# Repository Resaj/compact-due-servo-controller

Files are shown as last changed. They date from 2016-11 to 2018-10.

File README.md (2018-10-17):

# Compact Due servo controller
This is a redesigned Arduino Due for the control of any humanoid or articulated robot, controlled by PS3 bluetooth controller, with bluetooth dongle in the native port of the SAM3 microcontroller, 20 servomotor signals, UART and I2C for bus servomotors.

<p align="center">
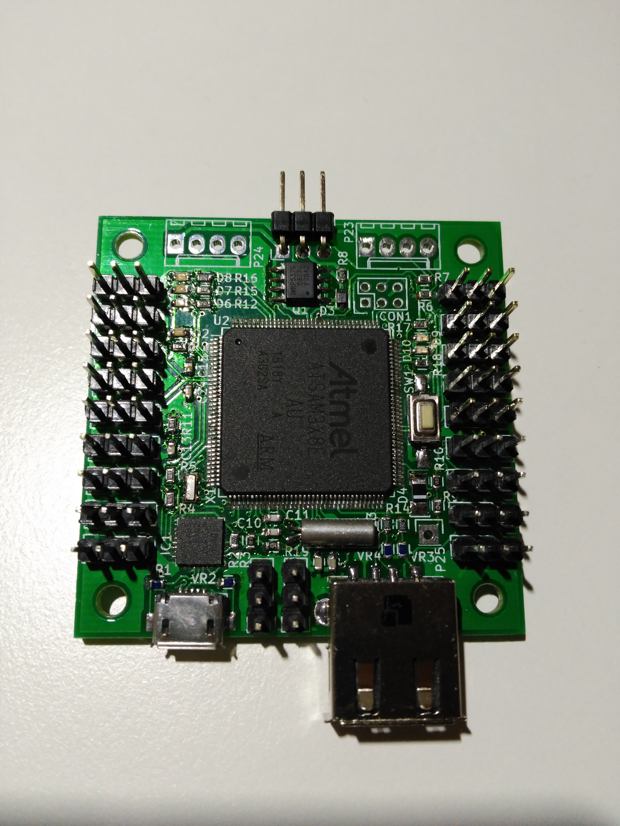
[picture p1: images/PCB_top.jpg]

</p>

<p align="center">
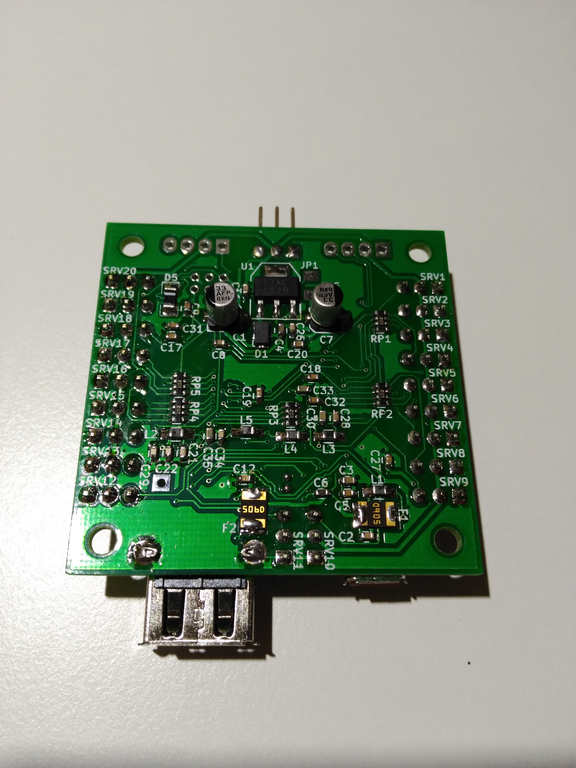
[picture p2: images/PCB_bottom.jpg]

</p>

<p align="center">
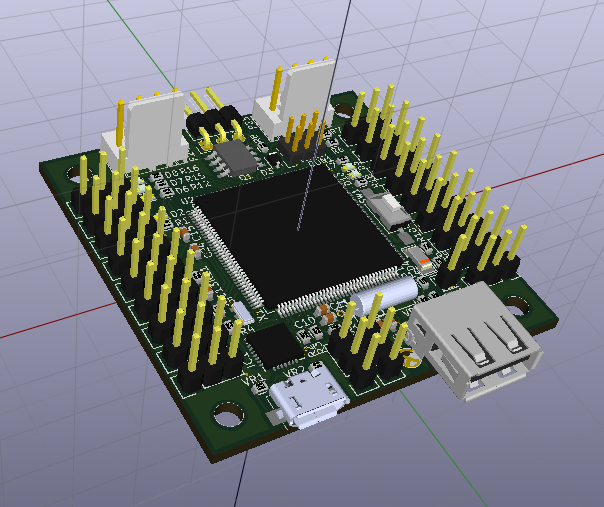
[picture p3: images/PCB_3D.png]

</p>

## Authors
[Rubén Espino San José](https://github.com/Resaj)

[Mario Luis Álvarez Pastor](https://github.com/AxomirUxsil)

## License
<p align="center">

</p>

Todos estos productos están liberados mediante [Creative Commons Attribution-ShareAlike 4.0 International License](http://creativecommons.org/licenses/by-sa/4.0/).  
_All these products are released under [Creative Commons Attribution-ShareAlike 4.0 International License](http://creativecommons.org/licenses/by-sa/4.0/)._

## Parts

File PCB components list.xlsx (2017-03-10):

Needed | Component | Quantity | Price per unit (€) | Total price (€) | Link
1 | diode SS1P3L | 50 | 0.079 | 3.95 | http://es.rs-online.com/web/p/diodos-schottky-y-rectificadores/7103695/
2 | capacitor 33uF | 10 | 0.114 | 1.14 | http://es.rs-online.com/web/p/condensadores-de-aluminio/0568852/
1 | MOSFET IRF7842PBF | 5 | 1.652 | 8.26 | http://es.rs-online.com/web/p/transistores-mosfet/6886879/
1 | zéner MM3Z12VT1G | 25 | 0.113 | 2.825 | http://es.rs-online.com/web/p/diodos-zener/6878219/
5 | array 4 resistor 0603 1k | 50 | 0.037 | 1.85 | http://es.rs-online.com/web/p/array-de-resistencias/5225579/
1 | conector uUSB SMD | 5 | 0.414 | 2.07 | http://es.rs-online.com/web/p/conectores-micro-usb/7142344/
2 | PTC 500mA | 10 | 0.306 | 3.06 | http://es.rs-online.com/web/p/fusibles-para-montaje-superficial-rearmables/6478156/
5 | PTC CG0603MLC-05LE | 25 | 0.106 | 2.65 | http://es.rs-online.com/web/p/varistores-de-oxido-metalico/6909938/
3 | inductor BLM21 | 25 | 0.021 | 0.525 | http://es.rs-online.com/web/p/nucleos-de-ferrita/7926300/
1 | driver CP2102-GM | 1 | 2.48 | 2.48 | http://es.rs-online.com/web/p/products/5268841/
1 | conector USB | 1 | 0.7 | 0.7 | http://es.rs-online.com/web/p/conectores-usb-tipo-a/7378791/
1 | diode CD1206-S01575 | 100 | 0.0326 | 3.26 | http://es.rs-online.com/web/p/diodos-schottky-y-rectificadores/7734514/
1 | uC ATSAM3X8E | 1 | 10.94 | 10.94 | http://es.rs-online.com/web/p/microcontroladores/7692527/
1 | resonator CSTCE12M0G15L99-R0 | 5 | 0.288 | 1.44 | http://es.rs-online.com/web/p/resonadores-ceramicos/7926527/
1 | crystal 32,768MHz | 10 | 0.40414 | 4.0414 | http://es.rs-online.com/web/p/unidades-de-cristal/5476985/
1 | LDO 3V3 LM3940IMP | 1 | 1.4399 | 1.4399 | http://es.rs-online.com/web/p/reguladores-de-tension-de-baja-caida/5361546/
1 | pushbutton SMD | 10 | 0.041 | 0.41 | https://es.aliexpress.com/store/product/10-100-pieces-lot-New-type-3-6-2-5-switch-SMD-smt-3x6x2-5mm/1248738_32714250239.html
IMPORTANT NOTES: |  | Resistors, capacitors and leds (all SMD 0603) haven't been included because buying them in kits in eBay or Aliexpress is cheaper
 |  | The list of components has been designed to make purchases cost-effective from 3 assemblied PCBs. For smaller purchases, look for another distributor
 |  |  | Subtotal (€) | 51.0413
 |  |  | Shipping cost (€) | 6.05
 |  |  | Total (€) | 57.0913

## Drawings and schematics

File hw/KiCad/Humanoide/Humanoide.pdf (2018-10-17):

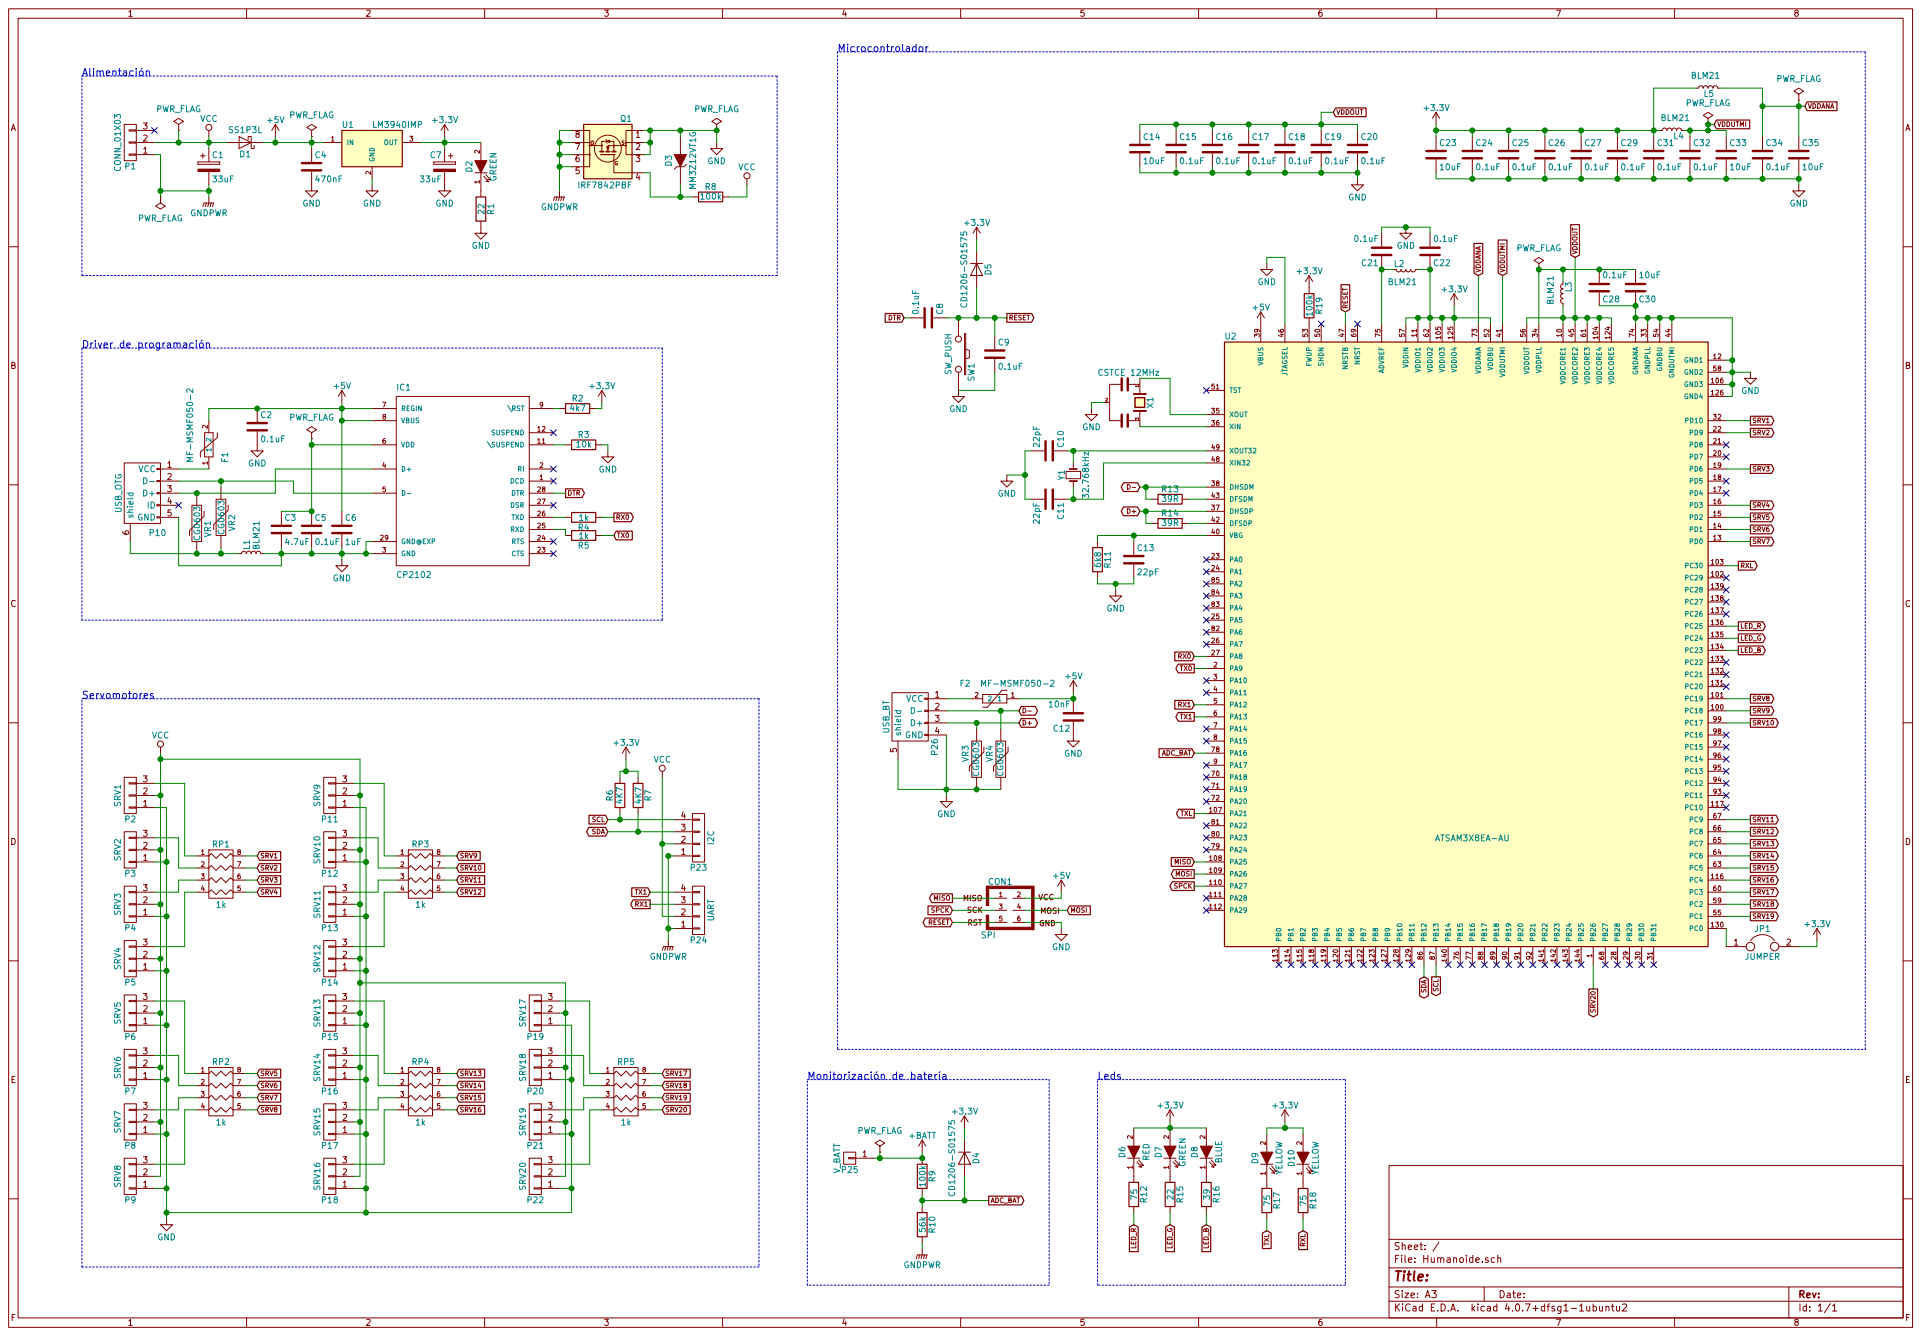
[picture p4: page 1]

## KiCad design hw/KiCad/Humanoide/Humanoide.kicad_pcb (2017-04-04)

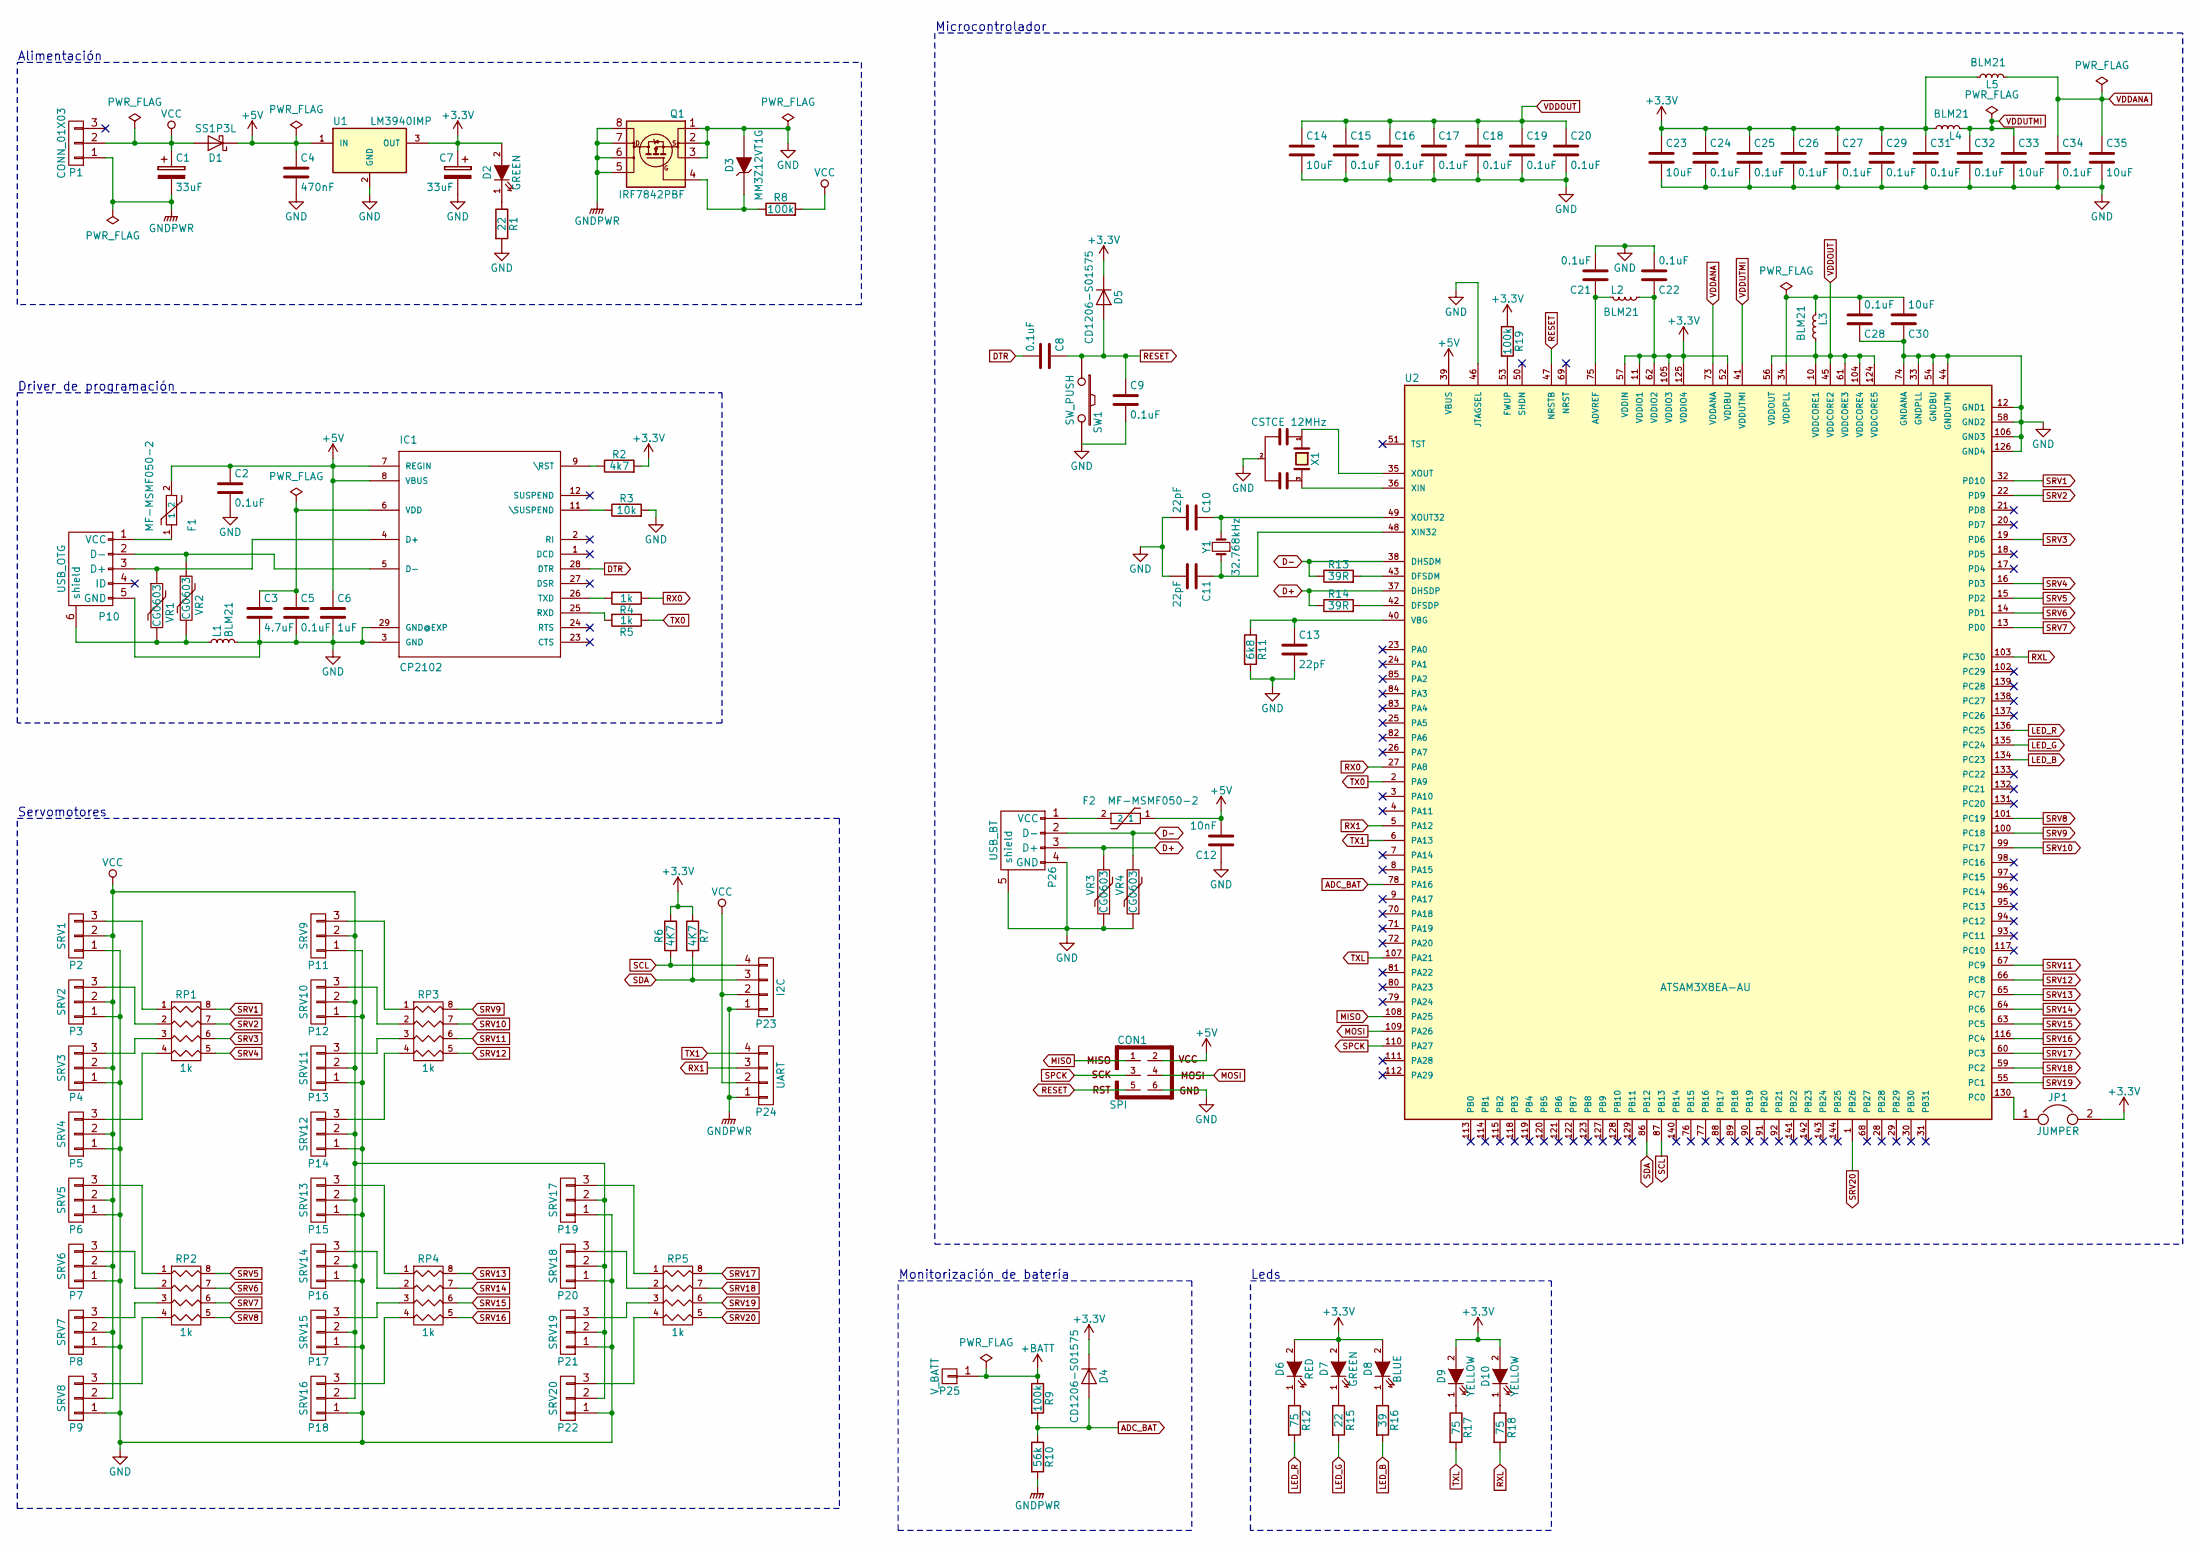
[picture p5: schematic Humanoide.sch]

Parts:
C1, C7: 33uF; c_elec_4x4.5
C2, C5, C8, C9, C15, C16, C17, C18, C19, C20, C21, C22, C24, C25, C26, C27, C28, C29, C31, C32, C34: 0.1uF; C_0603
C3: 4.7uF; C_0603
C4: 470nF; C_0603
C6: 1uF; C_0603
C10, C11, C13: 22pF; C_0603
C12: 10nF; C_0603
C14, C23, C30, C33, C35: 10uF; C_0603
CON1: SPI; Pin_Header_Straight_2x03_Pitch2.00mm
D1: SS1P3L; DO-220AA
D2, D7: GREEN; LED_0603
D3: MM3Z12VT1G; SOD-323
D4, D5: CD1206-S01575; SMD-1206_Pol
D6: RED; LED_0603
D8: BLUE; LED_0603
D9, D10: YELLOW; LED_0603
F1, F2: MF-MSMF050-2; Fuse_SMD
IC1: CP2102; QFN-28-1EP_5x5mm_Pitch0.5mm
JP1: JUMPER; Fuse_SMD1206_Wave
L1, L2, L3, L4, L5: BLM21; R_0805_HandSoldering
P1: CONN_01X03; Pin_Header_Angled_1x03
P2: SRV1; Pin_Header_Straight_1x03
P3: SRV2; Pin_Header_Straight_1x03
P4: SRV3; Pin_Header_Straight_1x03
P5: SRV4; Pin_Header_Straight_1x03
P6: SRV5; Pin_Header_Straight_1x03
P7: SRV6; Pin_Header_Straight_1x03
P8: SRV7; Pin_Header_Straight_1x03
P9: SRV8; Pin_Header_Straight_1x03
P10: USB_OTG; USB_micro-B
P11: SRV9; Pin_Header_Straight_1x03
P12: SRV10; Pin_Header_Straight_1x03
P13: SRV11; Pin_Header_Straight_1x03
P14: SRV12; Pin_Header_Straight_1x03
P15: SRV13; Pin_Header_Straight_1x03
P16: SRV14; Pin_Header_Straight_1x03
P17: SRV15; Pin_Header_Straight_1x03
P18: SRV16; Pin_Header_Straight_1x03
P19: SRV17; Pin_Header_Straight_1x03
P20: SRV18; Pin_Header_Straight_1x03
P21: SRV19; Pin_Header_Straight_1x03
P22: SRV20; Pin_Header_Straight_1x03
P23: I2C; Molex_KK-6410-04_04x2.54mm_Straight
P24: UART; Molex_KK-6410-04_04x2.54mm_Straight
P25: V_BATT; Pin_Header_Straight_1x01
P26: USB_BT; USB-A-SMD
Q1: IRF7842PBF; SOIC-8-N
R1, R15: 22; R_0603
R2: 4k7; R_0603
R3: 10k; R_0603
R4, R5: 1k; R_0603
R6, R7: 4K7; R_0603
R8, R9, R19: 100k; R_0603
R10: 56k; R_0603
R11: 6k8; R_0603
R12, R17, R18: 75; R_0603
R13, R14: 39R; R_0603
R16: 39; R_0603
RP1, RP2, RP3, RP4, RP5: 1k; R_Array_Convex_4x0603
SW1: SW_PUSH; SW_SPST_FSMSM
U1: LM3940IMP; SOT-223
U2: ATSAM3X8EA-AU; LQFP-144_20x20mm_Pitch0.5mm
VR1, VR2, VR3, VR4: CG0603; R_0603
X1: CSTCE 12MHz; Resonator_3.2x1.3mm
Y1: 32.768kHz; Crystal_Round_Horizontal_3mm

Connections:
+3V3: C7.1, C22.1, C23.1, C24.1, C25.1, C26.1, C27.1, C29.1, C31.1, D2.2 (A), D4.1 (K), D5.1 (K), D6.2 (A), D7.2 (A), D8.2 (A), D9.2 (A), D10.2 (A), JP1.2, L2.1, L4.1, L5.1, R2.2, R6.1, R7.1, R19.1, U1.3 (OUT), U2.11 (VDDIO1), U2.52 (VDDBU), U2.57 (VDDIN), U2.62 (VDDIO2), U2.105 (VDDIO3), U2.125 (VDDIO4)
+5V: C2.1, C4.1, C6.1, C12.2, CON1.2, D1.1 (K), F1.2, F2.1, IC1.7 (REGIN), IC1.8 (VBUS), U1.1 (IN), U2.39 (VBUS)
+BATT: P25.1, R9.1
ADC_BAT: D4.2 (A), R9.2, R10.1, U2.78 (PA16)
D+: P26.3 (D+), R14.1, U2.37 (DHSDP), VR3.2
D-: P26.2 (D-), R13.1, U2.38 (DHSDM), VR4.2
DTR: C8.2, IC1.28 (DTR)
GND: C2.2, C3.2, C4.2, C5.2, C6.2, C7.2, C9.2, C10.2, C11.2, C12.1, C13.2, C14.2, C15.2, C16.2, C17.2, C18.2, C19.2, C20.2, C21.2, C22.2, C23.2, C24.2, C25.2, C26.2, C27.2, C28.1, C29.2, C30.1, C31.2, C32.2, C33.2, C34.2, C35.2, CON1.6, D3.2 (A), IC1.3 (GND), IC1.29 (GND@EXP), L1.2, P2.1, P3.1, P4.1, P5.1, P6.1, P7.1, P8.1, P9.1, P10.5 (GND), P11.1, P12.1, P13.1, P14.1, P15.1, P16.1, P17.1, P18.1, P19.1, P20.1, P21.1, P22.1, P26.4 (GND), P26.5 (shield), Q1.1 (S), Q1.2 (S), Q1.3 (S), R1.2, R3.2, R11.2, SW1.2, U1.2 (GND), U2.12 (GND1), U2.33 (GNDPLL), U2.44 (GNDUTMI), U2.46 (JTAGSEL), U2.54 (GNDBU), U2.58 (GND2), U2.74 (GNDANA), U2.106 (GND3), U2.126 (GND4), VR3.1, VR4.1, X1.2
GNDPWR: C1.2, P1.1, P23.1, P24.1, Q1.5 (D), Q1.6 (D), Q1.7 (D), Q1.8 (D), R10.2
LED_B: R16.2, U2.134 (PC23)
LED_G: R15.2, U2.135 (PC24)
LED_R: R12.2, U2.136 (PC25)
MISO: CON1.1, U2.108 (PA25)
MOSI: CON1.4, U2.109 (PA26)
unnamed: C3.1, C5.1, IC1.6 (VDD)
unnamed: C10.1, U2.49 (XOUT32), Y1.2
unnamed: C11.1, U2.48 (XIN32), Y1.1
unnamed: C13.1, R11.1, U2.40 (VBG)
unnamed: C21.1, L2.2, U2.75 (ADVREF)
unnamed: C28.2, C30.2, L3.2, U2.34 (VDDPLL)
unnamed: D2.1 (K), R1.1
unnamed: D3.1 (K), Q1.4 (G), R8.1
unnamed: D6.1 (K), R12.1
unnamed: D7.1 (K), R15.1
unnamed: D8.1 (K), R16.1
unnamed: D9.1 (K), R17.1
unnamed: D10.1 (K), R18.1
unnamed: F1.1, P10.1 (VCC)
unnamed: F2.2, P26.1 (VCC)
unnamed: IC1.4 (D+), P10.3 (D+), VR1.1
unnamed: IC1.5 (D-), P10.2 (D-), VR2.1
unnamed: IC1.9 (\RST), R2.1
unnamed: IC1.11 (\SUSPEND), R3.1
unnamed: IC1.25 (RXD), R5.2
unnamed: IC1.26 (TXD), R4.2
unnamed: JP1.1, U2.130 (PC0)
unnamed: L1.1, P10.6 (shield), VR1.2, VR2.2
unnamed: P2.3, RP1.1
unnamed: P3.3, RP1.2
unnamed: P4.3, RP1.3
unnamed: P5.3, RP1.4
unnamed: P6.3, RP2.1
unnamed: P7.3, RP2.2
unnamed: P8.3, RP2.3
unnamed: P9.3, RP2.4
unnamed: P11.3, RP3.1
unnamed: P12.3, RP3.2
unnamed: P13.3, RP3.3
unnamed: P14.3, RP3.4
unnamed: P15.3, RP4.1
unnamed: P16.3, RP4.2
unnamed: P17.3, RP4.3
unnamed: P18.3, RP4.4
unnamed: P19.3, RP5.1
unnamed: P20.3, RP5.2
unnamed: P21.3, RP5.3
unnamed: P22.3, RP5.4
unnamed: R13.2, U2.43 (DFSDM)
unnamed: R14.2, U2.42 (DFSDP)
unnamed: R19.2, U2.53 (FWUP)
unnamed: U2.35 (XOUT), X1.1
unnamed: U2.36 (XIN), X1.3
RESET: C8.1, C9.1, CON1.5, D5.2 (A), SW1.1, U2.47 (NRSTB)
RX0: R4.1, U2.27 (PA8)
RX1: P24.3, U2.5 (PA12)
RXL: R18.2, U2.103 (PC30)
SCL: P23.4, R6.2, U2.87 (PB13)
SDA: P23.3, R7.2, U2.86 (PB12)
SPCK: CON1.3, U2.110 (PA27)
SRV1: RP1.8 (R1), U2.32 (PD10)
SRV2: RP1.7 (R2), U2.22 (PD9)
SRV3: RP1.6 (R3), U2.19 (PD6)
SRV4: RP1.5 (R4), U2.16 (PD3)
SRV5: RP2.8 (R1), U2.15 (PD2)
SRV6: RP2.7 (R2), U2.14 (PD1)
SRV7: RP2.6 (R3), U2.13 (PD0)
SRV8: RP2.5 (R4), U2.101 (PC19)
SRV9: RP3.8 (R1), U2.100 (PC18)
SRV10: RP3.7 (R2), U2.99 (PC17)
SRV11: RP3.6 (R3), U2.67 (PC9)
SRV12: RP3.5 (R4), U2.66 (PC8)
SRV13: RP4.8 (R1), U2.65 (PC7)
SRV14: RP4.7 (R2), U2.64 (PC6)
SRV15: RP4.6 (R3), U2.63 (PC5)
SRV16: RP4.5 (R4), U2.116 (PC4)
SRV17: RP5.8 (R1), U2.60 (PC3)
SRV18: RP5.7 (R2), U2.59 (PC2)
SRV19: RP5.6 (R3), U2.55 (PC1)
SRV20: RP5.5 (R4), U2.1 (PB26)
TX0: R5.1, U2.2 (PA9)
TX1: P24.4, U2.6 (PA13)
TXL: R17.2, U2.107 (PA21)
VCC: C1.1, D1.2 (A), P1.2, P2.2, P3.2, P4.2, P5.2, P6.2, P7.2, P8.2, P9.2, P11.2, P12.2, P13.2, P14.2, P15.2, P16.2, P17.2, P18.2, P19.2, P20.2, P21.2, P22.2, P23.2, P24.2, R8.2
VDDANA: C34.1, C35.1, L5.2, U2.73 (VDDANA)
VDDOUT: C14.1, C15.1, C16.1, C17.1, C18.1, C19.1, C20.1, L3.1, U2.10 (VDDCORE1), U2.45 (VDDCORE2), U2.56 (VDDOUT), U2.61 (VDDCORE3), U2.104 (VDDCORE4), U2.124 (VDDCORE5)
VDDUTMI: C32.1, C33.1, L4.2, U2.41 (VDDUTMI)

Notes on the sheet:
Alimentación
Driver de programación
Servomotores
Microcontrolador
Leds
Monitorización de batería

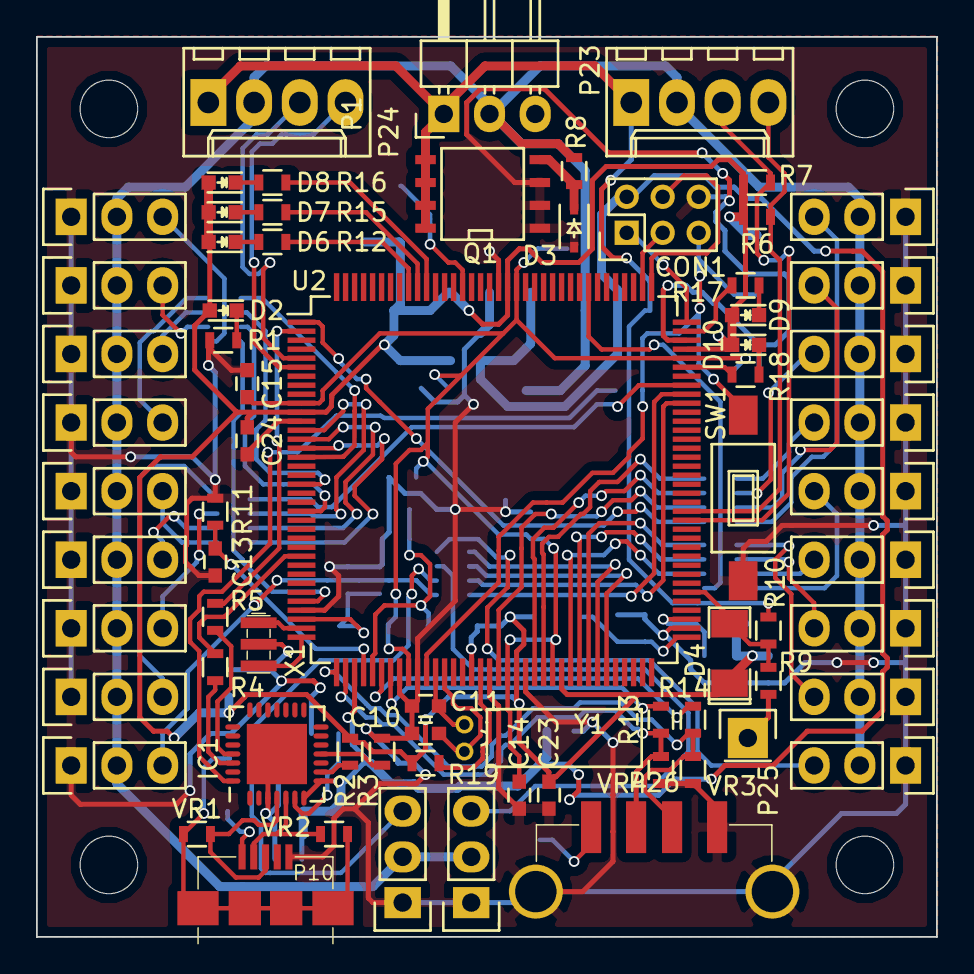
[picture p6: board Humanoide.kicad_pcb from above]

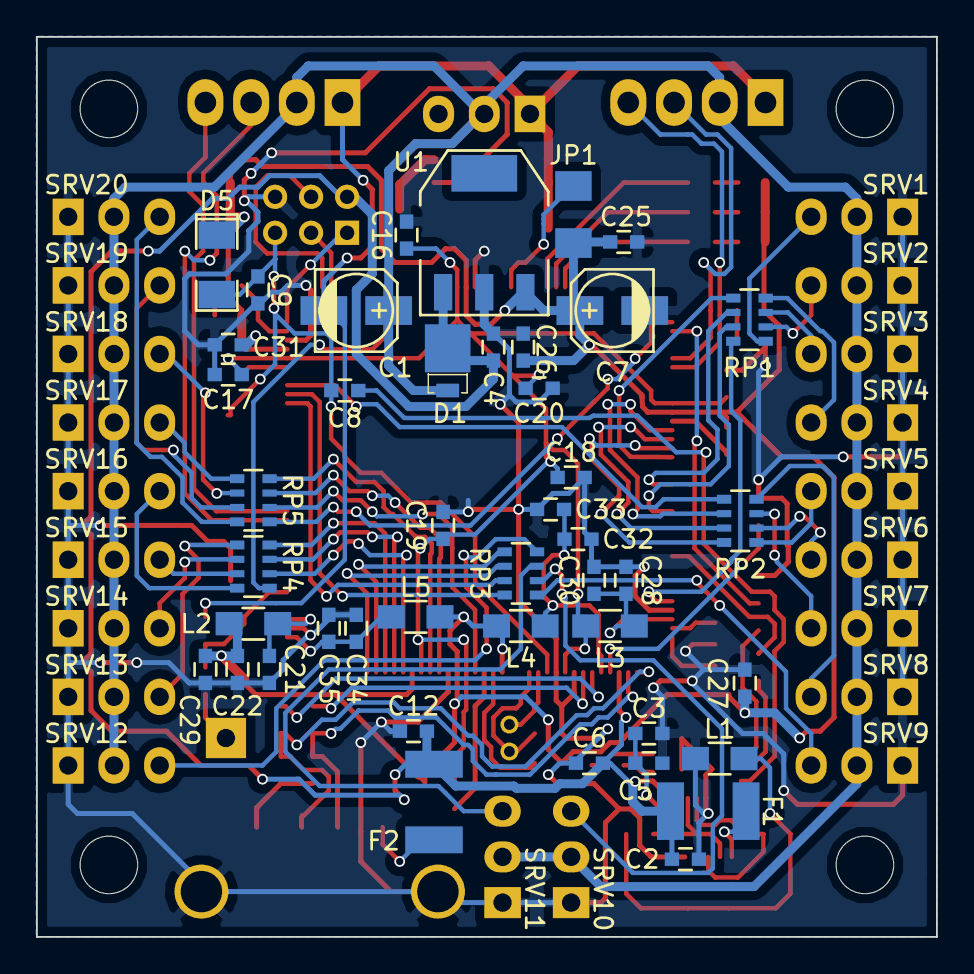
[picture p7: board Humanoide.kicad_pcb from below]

Board: 2 copper layers, 50.0 x 50.0 mm, 115 parts (44 on the bottom side), 96 nets.

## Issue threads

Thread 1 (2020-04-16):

PS3,Bluetooth code or libraries?

richaeell, 2020-04-16:
Hi, very nice board,
Im currently using the same chip and trying to port the Host Library of the AVR platform to connect a PS3 controller with USB or bluetooth, I was wondering if you guys had a idea or a library at hand to get it working.

Thanks.

Resaj, 2020-04-17:
Hi richaeell,

I was going to work on the libraries basing on other Github projects, such as https://github.com/arduino-libraries/USBHost/issues/24 and https://github.com/felis/USB_Host_Shield_2.0.

The bluetooth communication through the USB host is the main obstacle, but the project has been stopped due to lack of time.

So if you find any valid library for this purpose I would appreciate your contribution.

Best regards

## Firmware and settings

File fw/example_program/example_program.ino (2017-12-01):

#include <Servo.h>
#include "actuators.h"

void setup()
{
  Serial.begin(115200);

  servo_config(SHOULDER_L, 22);
  servo_config(SHOULDER_R, 25);
  servo_config(ARM_L, 26);
  servo_config(ARM_R, 27);
  servo_config(ELBOW_L, 28);
  servo_config(ELBOW_R, 29);
  servo_config(HIP_L, 30);
  servo_config(HIP_R, 32);
  servo_config(LEG_L, 33);
  servo_config(LEG_R, 34);
  servo_config(KNEE_L, 35);
  servo_config(KNEE_R, 36);

  servo_config(ANKLE_L, 37);
  servo_config(ANKLE_R, 38);
  servo_config(FOOT_L, 39);
  servo_config(FOOT_R, 40);
}

void loop()
{ 
  int pos = 0;
  
  for(pos = 45; pos <= 135; pos += 1)
  {
    servo_set(SHOULDER_L, pos);
    servo_set(SHOULDER_R, pos);
    servo_set(ARM_L, pos);
    servo_set(ARM_R, pos);
    servo_set(ELBOW_L, pos);
    servo_set(ELBOW_R, pos);
    servo_set(HIP_L, pos);
    servo_set(HIP_R, pos);
    servo_set(LEG_L, pos);
    servo_set(LEG_R, pos);
    servo_set(KNEE_L, pos);
    servo_set(KNEE_R, pos);
    servo_set(ANKLE_L, pos);
    servo_set(ANKLE_R, pos);
    servo_set(FOOT_L, pos);
    servo_set(FOOT_R, pos);
    delay(15);
  } 
  for(pos = 135; pos>=45; pos-=1)
  {                                
    servo_set(SHOULDER_L, pos);
    servo_set(SHOULDER_R, pos);
    servo_set(ARM_L, pos);
    servo_set(ARM_R, pos);
    servo_set(ELBOW_L, pos);
    servo_set(ELBOW_R, pos);
    servo_set(HIP_L, pos);
    servo_set(HIP_R, pos);
    servo_set(LEG_L, pos);
    servo_set(LEG_R, pos);
    servo_set(KNEE_L, pos);
    servo_set(KNEE_R, pos);
    servo_set(ANKLE_L, pos);
    servo_set(ANKLE_R, pos);
    servo_set(FOOT_L, pos);
    servo_set(FOOT_R, pos);
    delay(15);
  } 
}

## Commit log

2017-03-06 Update Kicad Readme
    [Humanoide_ordenado.kicad_pcb]
2017-03-08 PCB actualized with relative paths
    [Crystal 32kHz.stl, Humanoide.kicad_pcb, PTC 500mA.stl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]
2017-03-10 Kicad 3D model changed
    [Crystal 32kHz.stl, Humanoide.kicad_pcb, Humanoide.sch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]
2017-04-04 3D PCB model added
    [Humanoide.kicad_pcb]
2017-12-01 Example program adapted for Arduino Due
2018-10-17 Schematic added
    [Humanoide.sch]
2018-10-17 project reorganized
    [Humanoide.kicad_pcb, Humanoide.sch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]
